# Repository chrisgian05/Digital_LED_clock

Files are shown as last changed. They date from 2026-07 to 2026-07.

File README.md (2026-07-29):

# Digital LED Clock

A 6-digit 7-segment clock (HH:MM:SS) built around an ATmega328P, an
external RTC, and a constant-current LED driver — split across two
custom PCBs I designed in KiCad. This was mostly an excuse to actually
use everything I've learned so far about digital electronics and
embedded C in one project I could see and touch, instead of another
breadboard that gets torn down at the end of the semester.

## What it does

- Shows time as HH:MM:SS across 6 seven-segment digits
- Keeps time with a DS3231 RTC (accurate even when the board is
  powered off, thanks to a coin cell)
- 4 buttons: set hour, set minute, reset seconds, and toggle to show
  the DS3231's built-in temperature reading instead of the time
- Multiplexed display — only one digit is physically powered at a
  time, cycled fast enough (~166Hz) that it looks fully lit

## Hardware

Two boards, connected by a short ribbon cable:

- **`clock_board`** — the "brains." ATmega328P, DS3231 RTC, a 74HC595
  shift register + 6 transistors for digit selection, an ISP header
  for programming, and the 4 push buttons.
- **`led_board`** — the "face." A TLC5916 constant-current LED driver
  feeding three 2-digit common-anode 7-segment modules (6 digits
  total), plus the transistor-switched power lines coming in from the
  clock board.

Full schematics and PCB layouts are in [`hardware/`](hardware/), one
subfolder per board. Both were designed from scratch in KiCad — no
dev-board shields, no premade modules other than the RTC/driver ICs
themselves.

## Firmware

Bare-metal AVR C — no Arduino core, straight `avr-libc` and direct
register access. I wanted to actually deal with I2C, timers, and
interrupts myself instead of hiding behind `Wire.h` and `digitalWrite`.

- **`twi.c`** — hardware I2C driver for talking to the DS3231
- **`ds3231.c`** — RTC register access (BCD conversion, get/set time, temperature)
- **`display.c`** — 7-segment font table + the Timer1 interrupt that handles
  digit multiplexing (bit-banging both the 74HC595 and TLC5916 shift chains)
- **`buttons.c`** — debounced button reads with auto-repeat on hold
- **`main.c`** — main loop tying it all together

All of it lives in [`firmware/`](firmware/), buildable with either the
included `Makefile` or `platformio.ini`.

## Status

Schematics and PCBs are designed; firmware is written and reviewed but
**not yet validated on the assembled board** (still waiting on
boards/soldering as of writing this). A couple of polarity assumptions
(digit-select active-high/low, segment driver active-high/low) are
flagged with `#define`s in `firmware/src/config.h` specifically because
they're easier to confirm with a multimeter on the real board than to
guess from a schematic.

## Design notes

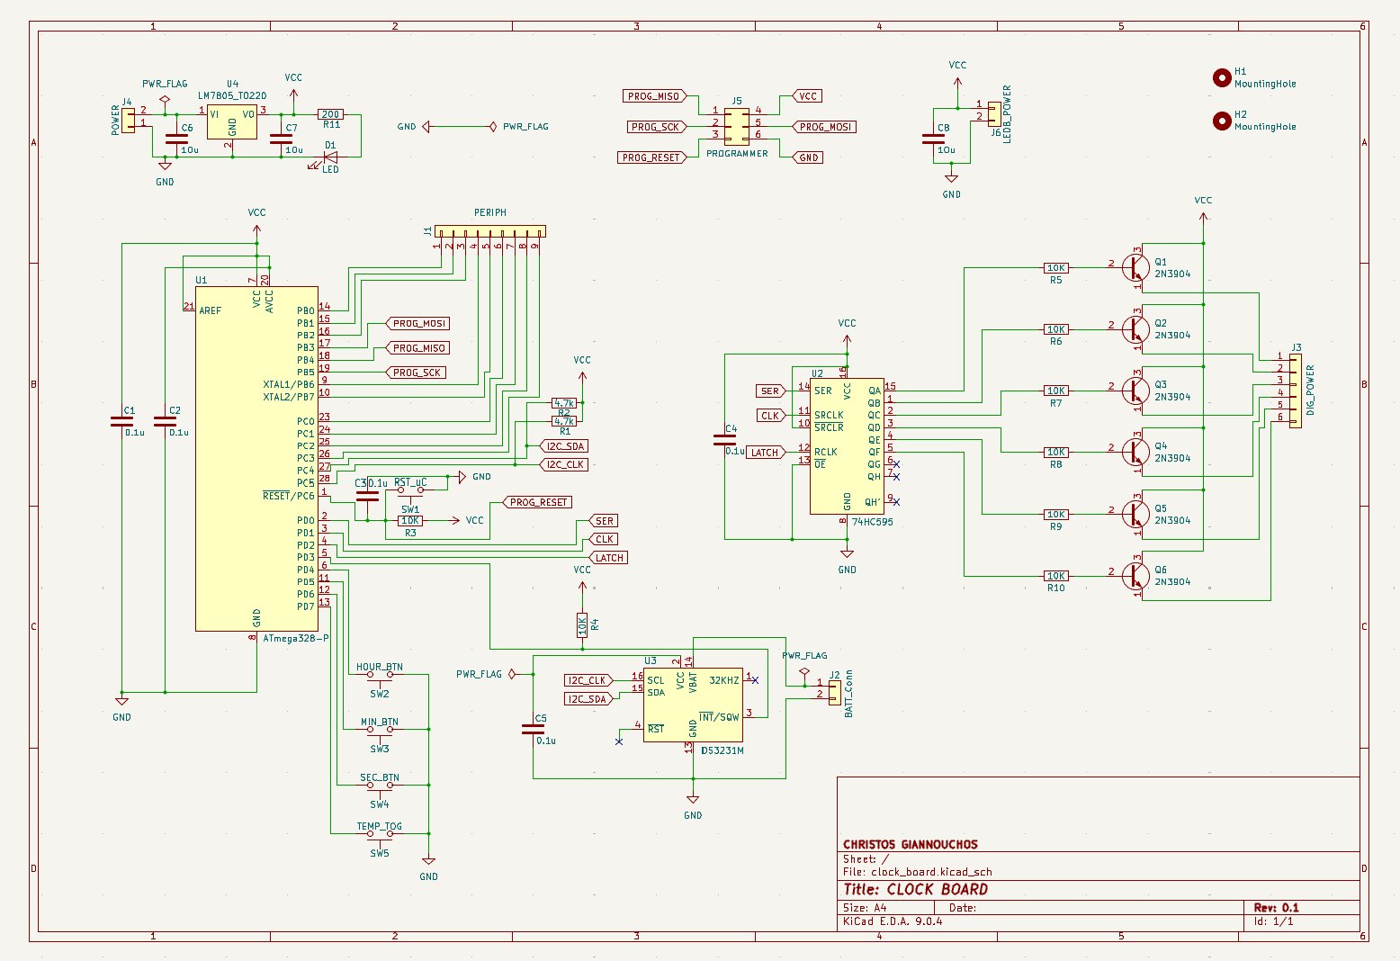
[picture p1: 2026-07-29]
hardware/clock_board/schematic.png

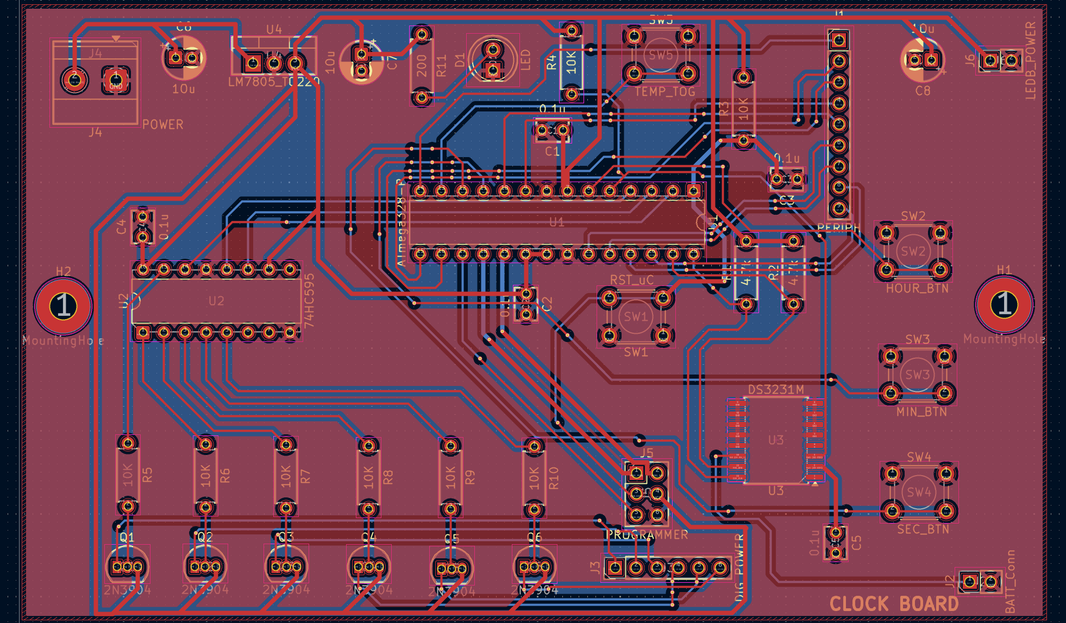
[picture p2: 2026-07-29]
hardware/clock_board/board.png

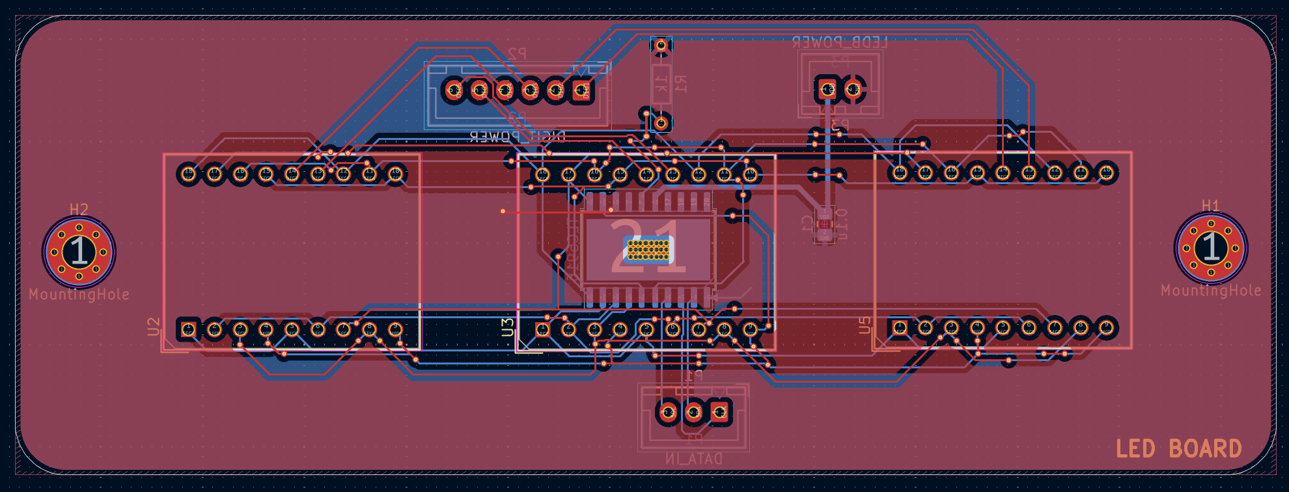
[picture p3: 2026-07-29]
hardware/led_board/board.png

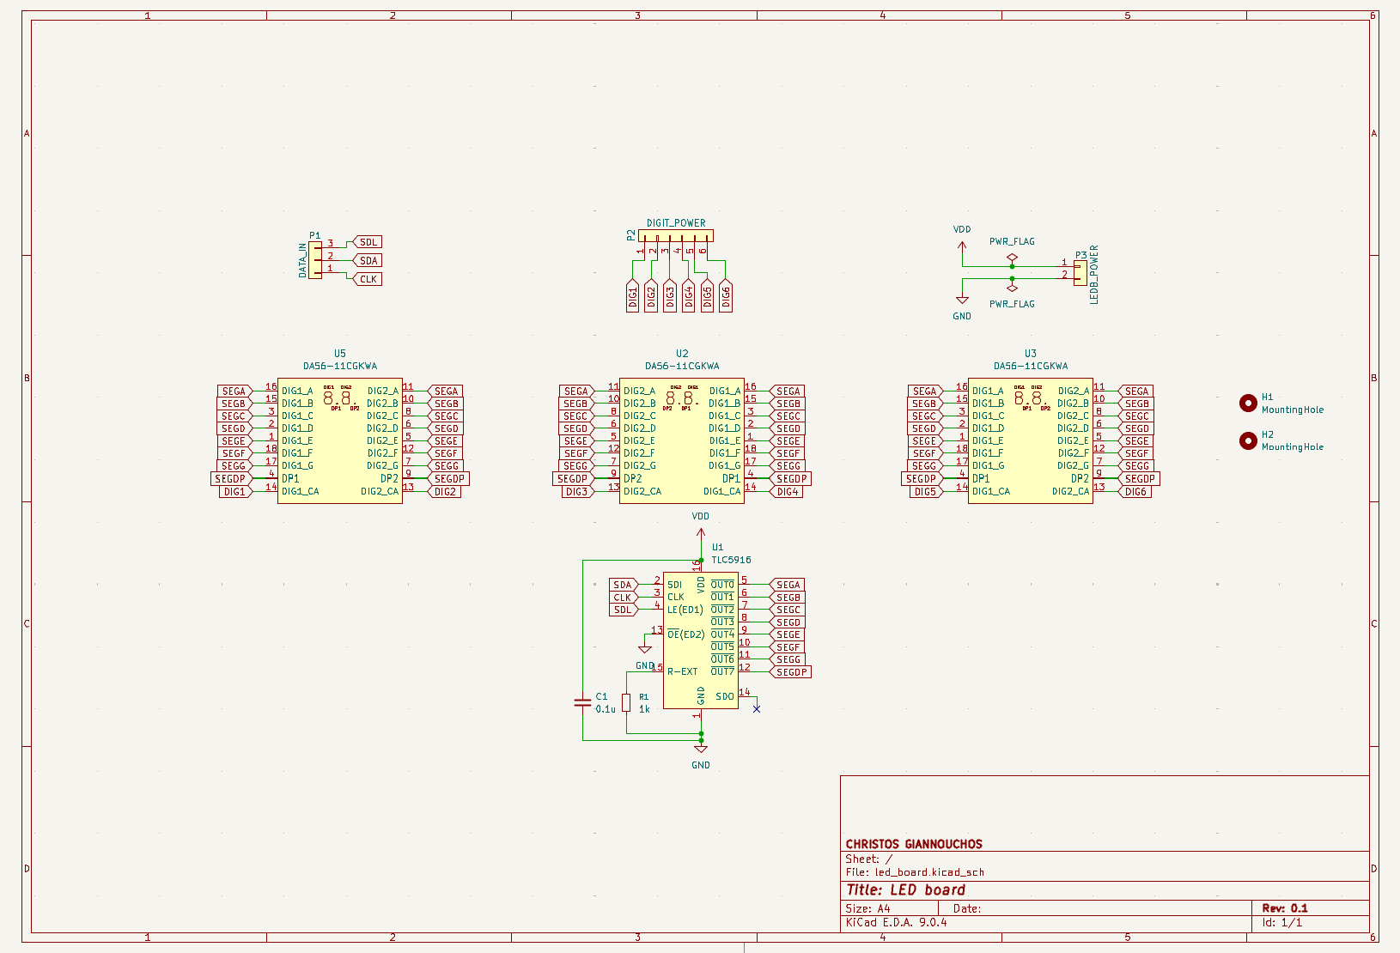
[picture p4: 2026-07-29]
hardware/led_board/schematic.png

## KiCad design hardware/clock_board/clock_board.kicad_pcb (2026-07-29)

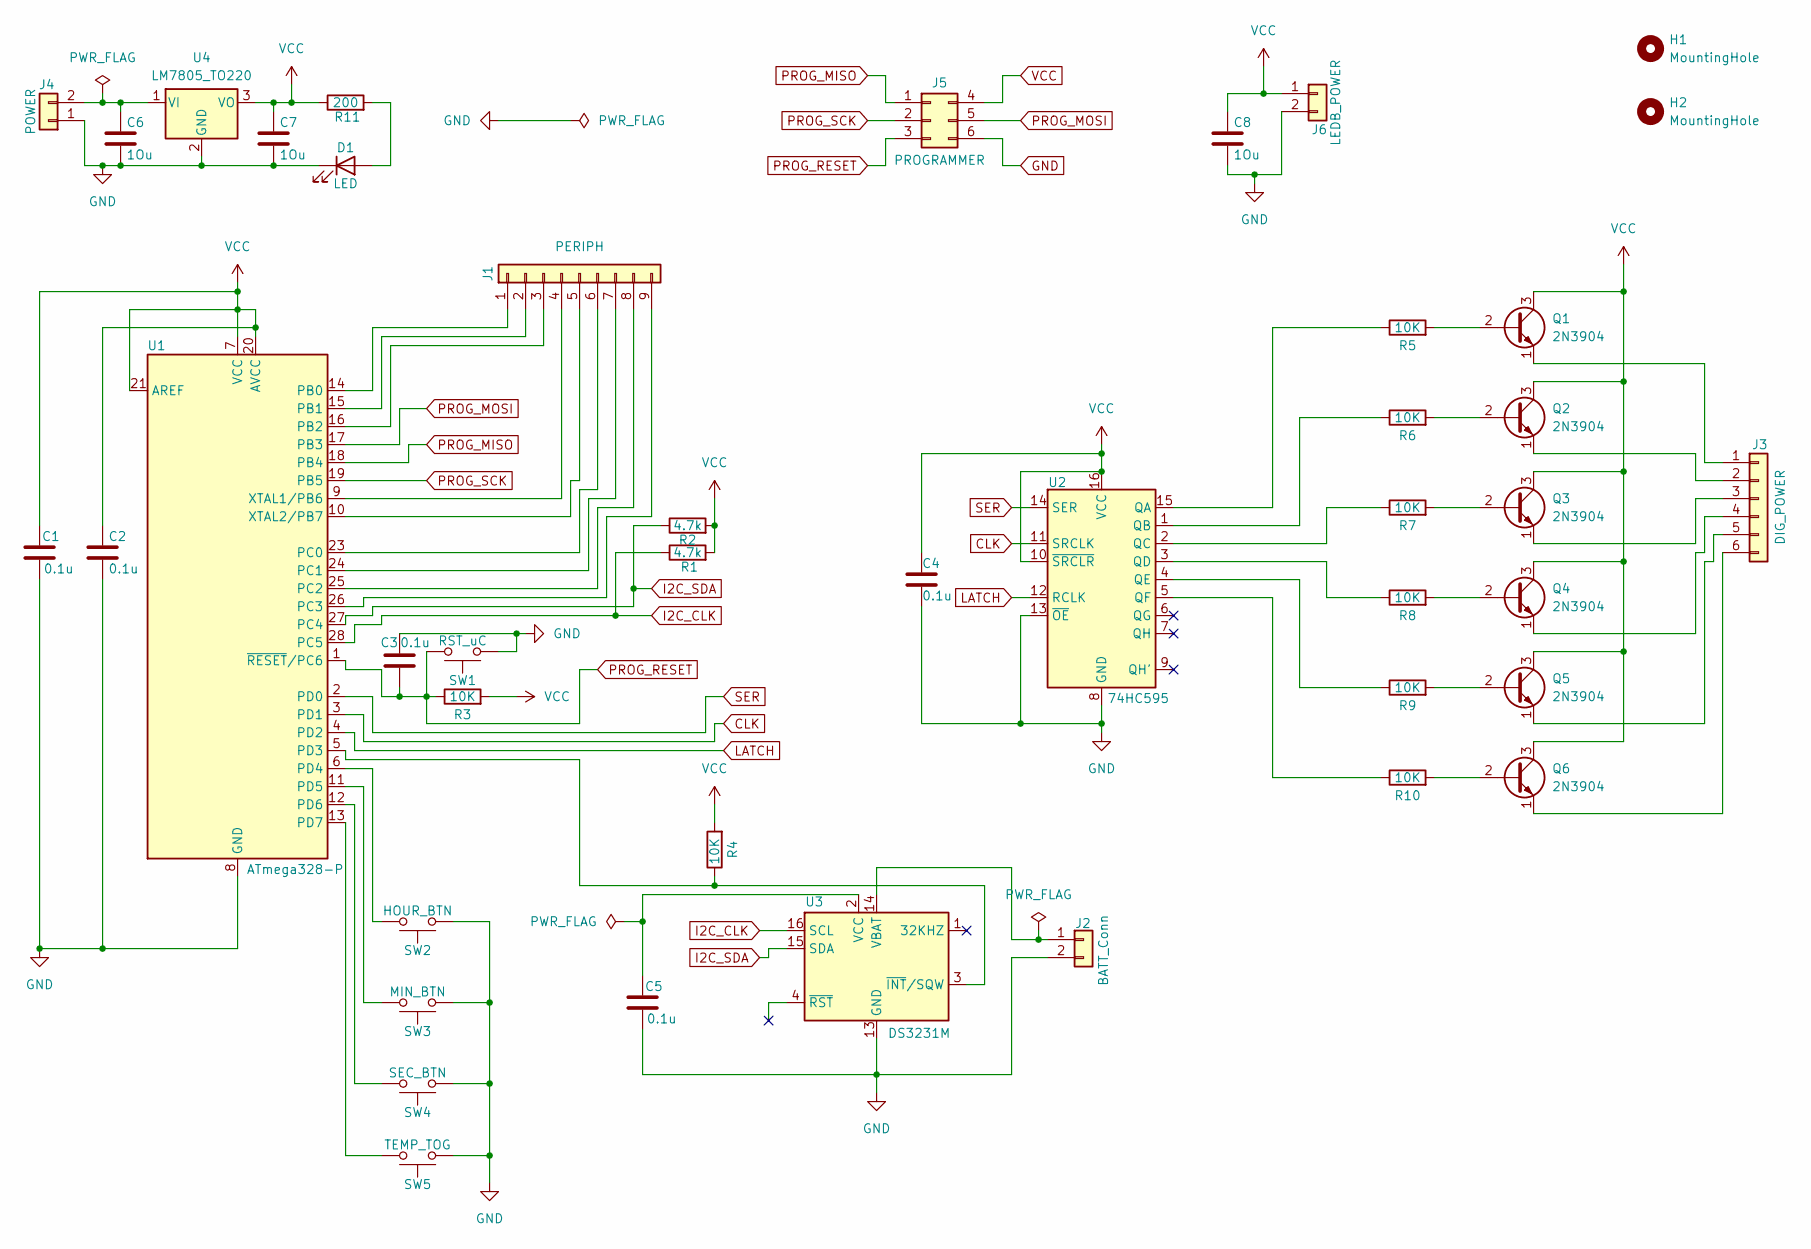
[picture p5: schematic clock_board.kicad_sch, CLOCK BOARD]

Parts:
C1, C2, C3, C4, C5: 0.1u; C_Disc_D3.8mm_W2.6mm_P2.50mm
C6, C7, C8: 1Ou; CP_Radial_D5.0mm_P2.00mm
D1: LED; LED_D5.0mm
H1, H2: MountingHole; MountingHole_3.2mm_M3_Pad
J1: PERIPH; PinHeader_1x09_P2.54mm_Vertical
J2: BATT_Conn; PinHeader_1x02_P2.54mm_Vertical
J3: DIG_POWER; PinHeader_1x06_P2.54mm_Vertical
J4: POWER; TerminalBlock_Phoenix_MKDS-1,5-2_1x02_P5.00mm_Horizontal
J5: PROGRAMMER; PinHeader_2x03_P2.54mm_Vertical
J6: LEDB_POWER; PinHeader_1x02_P2.54mm_Vertical
Q1, Q2, Q3, Q4, Q5, Q6: 2N3904; TO-92_Inline
R1, R2: 4.7k; R_Axial_DIN0207_L6.3mm_D2.5mm_P7.62mm_Horizontal
R3, R4, R5, R6, R7, R8, R9, R10: 10K; R_Axial_DIN0207_L6.3mm_D2.5mm_P7.62mm_Horizontal
R11: 200; R_Axial_DIN0207_L6.3mm_D2.5mm_P7.62mm_Horizontal
SW1: RST_uC; SW_PUSH_6mm_H5mm
SW2: HOUR_BTN; SW_PUSH_6mm_H5mm
SW3: MIN_BTN; SW_PUSH_6mm_H5mm
SW4: SEC_BTN; SW_PUSH_6mm_H5mm
SW5: TEMP_TOG; SW_PUSH_6mm_H5mm
U1: ATmega328-P; DIP-28_W7.62mm
U2: 74HC595; CERDIP-16_W7.62mm_SideBrazed
U3: DS3231M; SOIC-16W_7.5x10.3mm_P1.27mm
U4: LM7805_TO220; TO-220-3_Vertical

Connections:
CLK: U1.3 (PD1), U2.11 (SRCLK)
GND: C1.2, C2.2, C3.1, C4.2, C5.2, C6.2, C7.2, C8.2, D1.1 (K), J2.2, J4.1, J5.6, J6.2, SW1.1, SW2.1, SW3.1, SW4.1, SW5.1, U1.8 (GND), U1.22 (GND), U2.8 (GND), U2.13 (~OE), U3.5 (GND), U3.6 (GND), U3.7 (GND), U3.8 (GND), U3.9 (GND), U3.10 (GND), U3.11 (GND), U3.12 (GND), U3.13 (GND), U4.2 (GND)
I2C_CLK: R1.1, U1.28 (PC5), U3.16 (SCL)
I2C_SDA: R2.1, U1.27 (PC4), U3.15 (SDA)
LATCH: U1.4 (PD2), U2.12 (RCLK)
unnamed: D1.2 (A), R11.2
unnamed: J1.1, U1.14 (PB0)
unnamed: J1.2, U1.15 (PB1)
unnamed: J1.3, U1.16 (PB2)
unnamed: J1.4, U1.9 (XTAL1/PB6)
unnamed: J1.5, U1.10 (XTAL2/PB7)
unnamed: J1.6, U1.23 (PC0)
unnamed: J1.7, U1.24 (PC1)
unnamed: J1.8, U1.25 (PC2)
unnamed: J1.9, U1.26 (PC3)
unnamed: J2.1, U3.14 (VBAT)
unnamed: J3.1, Q1.1 (E)
unnamed: J3.2, Q2.1 (E)
unnamed: J3.3, Q3.1 (E)
unnamed: J3.4, Q4.1 (E)
unnamed: J3.5, Q5.1 (E)
unnamed: J3.6, Q6.1 (E)
unnamed: C6.1, J4.2, U4.1 (VI)
unnamed: Q1.2 (B), R5.2
unnamed: Q2.2 (B), R6.2
unnamed: Q3.2 (B), R7.2
unnamed: Q4.2 (B), R8.2
unnamed: Q5.2 (B), R9.2
unnamed: Q6.2 (B), R10.2
unnamed: R4.1, U1.5 (PD3), U3.3 (~INT/SQW)
unnamed: SW2.2, U1.6 (PD4)
unnamed: SW3.2, U1.11 (PD5)
unnamed: SW4.2, U1.12 (PD6)
unnamed: SW5.2, U1.13 (PD7)
unnamed: R5.1, U2.15 (QA)
unnamed: R6.1, U2.1 (QB)
unnamed: R7.1, U2.2 (QC)
unnamed: R8.1, U2.3 (QD)
unnamed: R9.1, U2.4 (QE)
unnamed: R10.1, U2.5 (QF)
unnamed: C5.1, U3.2 (VCC)
PROG_MISO: J5.1, U1.18 (PB4)
PROG_MOSI: J5.5, U1.17 (PB3)
PROG_RESET: C3.2, J5.3, R3.1, SW1.2, U1.1 (~RESET/PC6)
PROG_SCK: J5.2, U1.19 (PB5)
SER: U1.2 (PD0), U2.14 (SER)
VCC: C1.1, C2.1, C4.1, C7.1, C8.1, J5.4, J6.1, Q1.3 (C), Q2.3 (C), Q3.3 (C), Q4.3 (C), Q5.3 (C), Q6.3 (C), R1.2, R2.2, R3.2, R4.2, R11.1, U1.7 (VCC), U1.20 (AVCC), U1.21 (AREF), U2.10 (~SRCLR), U2.16 (VCC), U4.3 (VO)

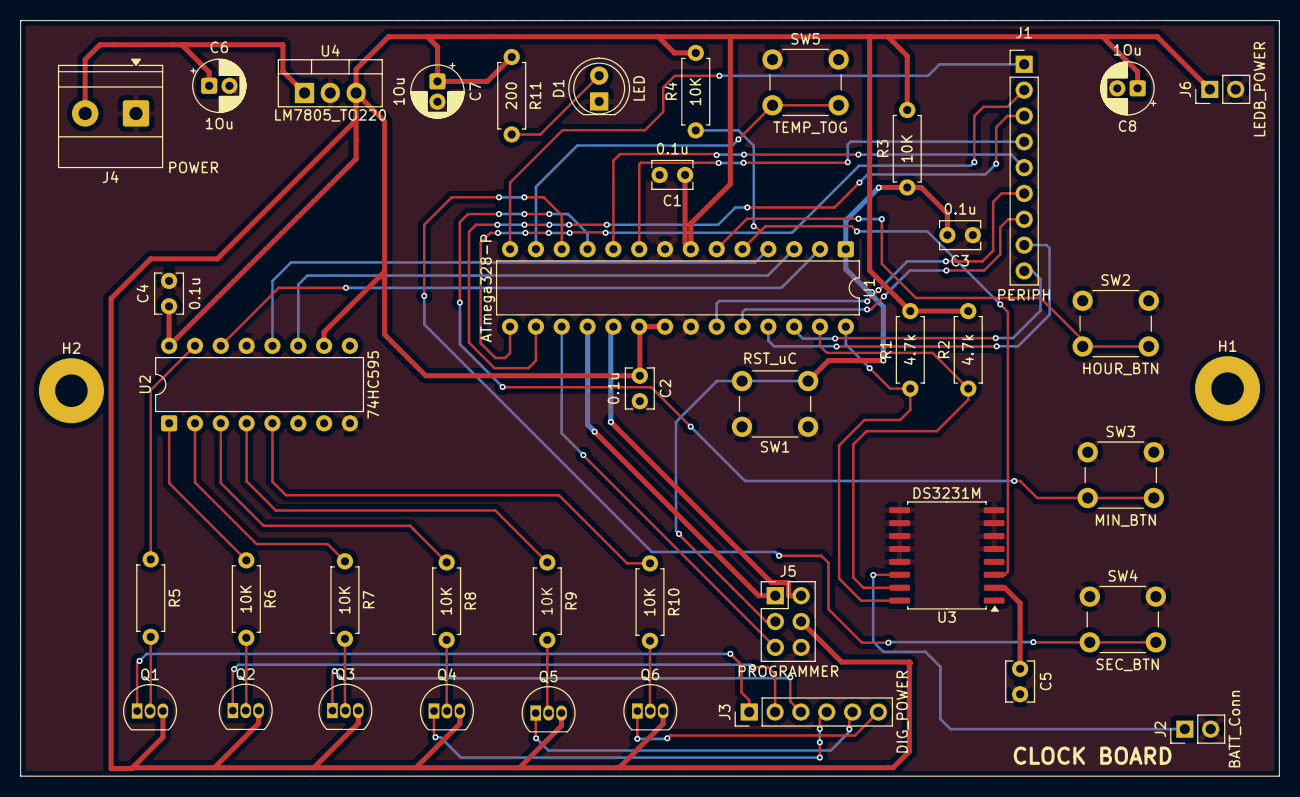
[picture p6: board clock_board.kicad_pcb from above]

Board: 2 copper layers, 123.8 x 74.3 mm, 43 parts (0 on the bottom side), 47 nets.

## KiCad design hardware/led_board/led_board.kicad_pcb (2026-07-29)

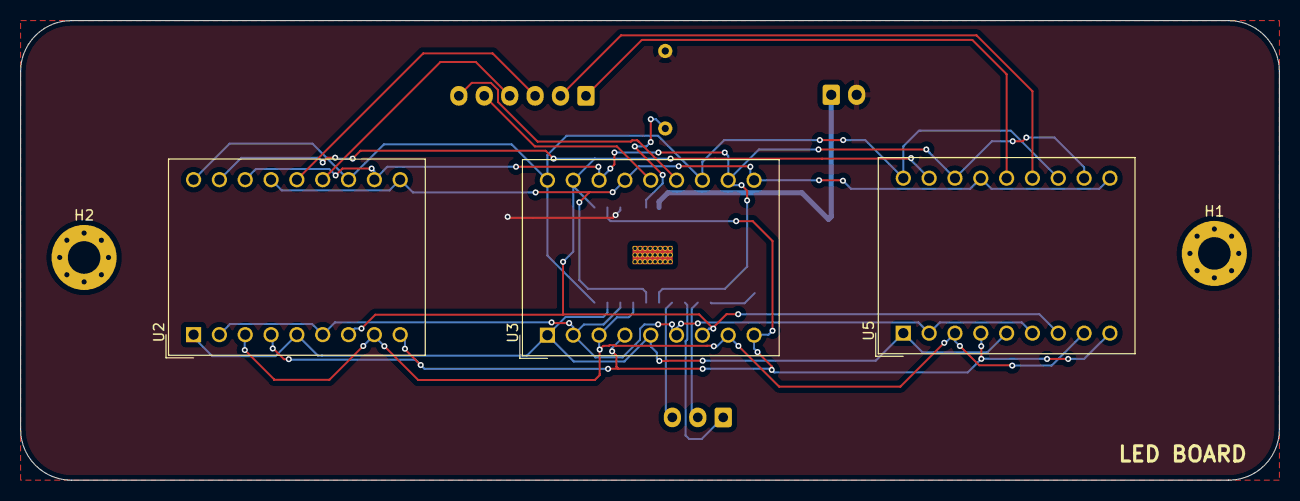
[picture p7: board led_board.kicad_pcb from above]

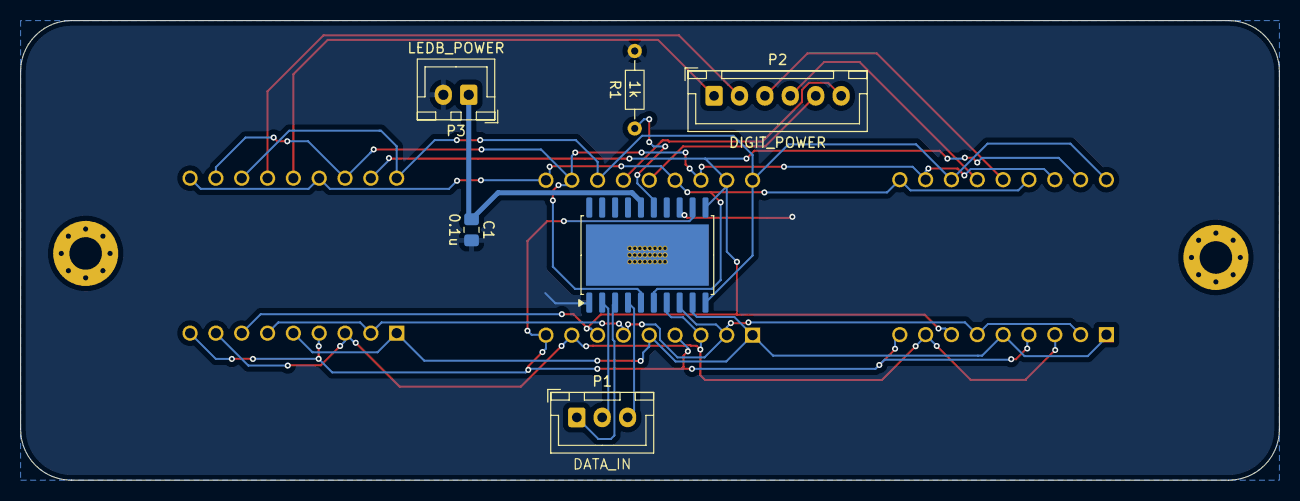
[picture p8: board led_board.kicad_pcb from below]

Board: 2 copper layers, 123.8 x 45.2 mm, 11 parts (6 on the bottom side), 20 nets.

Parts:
C1: 0.1u; C_0805_2012Metric_Pad1.18x1.45mm_HandSolder
H1, H2: MountingHole; MountingHole_3.2mm_M3_Pad_Via
P1: DATA_IN; JST_XH_B3B-XH-A_1x03_P2.50mm_Vertical
P2: DIGIT_POWER; JST_XH_B6B-XH-A_1x06_P2.50mm_Vertical
P3: LEDB_POWER; JST_XH_B2B-XH-A_1x02_P2.50mm_Vertical
R1: 1k; R_Axial_DIN0204_L3.6mm_D1.6mm_P7.62mm_Horizontal
U1: TLC5916; SO-20-1EP_7.52x12.825mm_P1.27mm_EP6.045x12.09mm_Mask3.56x4.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
U2, U3, U5: DA56-11CGKWA

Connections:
CLK: P1.1, U1.3 (CLK)
DIG1: P2.1, U5.14 (DIG1_CA)
DIG2: P2.2, U5.13 (DIG2_CA)
DIG3: P2.3, U2.14 (DIG1_CA)
DIG4: P2.4, U2.13 (DIG2_CA)
DIG5: P2.5, U3.14 (DIG1_CA)
DIG6: P2.6, U3.13 (DIG2_CA)
GND: C1.2, P3.2, R1.2, U1.1 (GND), U1.13 (~OE(ED2))
unnamed: R1.1, U1.15 (R-EXT)
SDA: P1.2, U1.2 (SDI)
SDL: P1.3, U1.4 (LE(ED1))
SEGA: U1.5 (~OUT0), U2.11 (DIG2_A), U2.16 (DIG1_A), U3.11 (DIG2_A), U3.16 (DIG1_A), U5.11 (DIG2_A), U5.16 (DIG1_A)
SEGB: U1.6 (~OUT1), U2.10 (DIG2_B), U2.15 (DIG1_B), U3.10 (DIG2_B), U3.15 (DIG1_B), U5.10 (DIG2_B), U5.15 (DIG1_B)
SEGC: U1.7 (~OUT2), U2.3 (DIG1_C), U2.8 (DIG2_C), U3.3 (DIG1_C), U3.8 (DIG2_C), U5.3 (DIG1_C), U5.8 (DIG2_C)
SEGD: U1.8 (~OUT3), U2.2 (DIG1_D), U2.6 (DIG2_D), U3.2 (DIG1_D), U3.6 (DIG2_D), U5.2 (DIG1_D), U5.6 (DIG2_D)
SEGDP: U1.12 (~OUT7), U2.4 (DP1), U2.9 (DP2), U3.4 (DP1), U3.9 (DP2), U5.4 (DP1), U5.9 (DP2)
SEGE: U1.9 (~OUT4), U2.1 (DIG1_E), U2.5 (DIG2_E), U3.1 (DIG1_E), U3.5 (DIG2_E), U5.1 (DIG1_E), U5.5 (DIG2_E)
SEGF: U1.10 (~OUT5), U2.12 (DIG2_F), U2.18 (DIG1_F), U3.12 (DIG2_F), U3.18 (DIG1_F), U5.12 (DIG2_F), U5.18 (DIG1_F)
SEGG: U1.11 (~OUT6), U2.7 (DIG2_G), U2.17 (DIG1_G), U3.7 (DIG2_G), U3.17 (DIG1_G), U5.7 (DIG2_G), U5.17 (DIG1_G)
VDD: C1.1, P3.1, U1.16 (VDD)

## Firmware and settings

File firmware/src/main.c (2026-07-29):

#include "config.h"
#include "twi.h"
#include "ds3231.h"
#include "display.h"
#include "buttons.h"
#include <avr/interrupt.h>

#define RTC_POLL_INTERVAL_MS   200  /* how often we re-read HH:MM:SS   */
#define TEMP_POLL_INTERVAL_MS  1000 /* DS3231 only updates temp ~64s   */

int main(void)
{
    twi_init();
    ds3231_init();      /* if this returns 0, the RTC isn't answering -
                          * time will just read back as whatever junk
                          * twi_read_regs left in the struct (likely all
                          * zero), which is harmless, it'll just show
                          * 00:00:00 until you fix the wiring. */
    display_init();
    buttons_init();
    sei();               /* enable interrupts -> Timer1 multiplex ISR starts */

    rtc_time_t cur_time = {0, 0, 0};
    int16_t    cur_tenths_c = 0;
    uint8_t    show_temp = 0;

    uint32_t last_rtc_poll  = 0;
    uint32_t last_temp_poll = 0;

    for (;;) {
        uint8_t events = buttons_poll();
        uint8_t time_changed = 0;

        if (events & BTN_EVT_HOUR) {
            cur_time.hour = (uint8_t)((cur_time.hour + 1) % 24);
            time_changed = 1;
        }
        if (events & BTN_EVT_MIN) {
            cur_time.minute = (uint8_t)((cur_time.minute + 1) % 60);
            time_changed = 1;
        }
        if (events & BTN_EVT_SEC) {
            /* Classic "seconds reset" behaviour: snaps the RTC to the
             * top of the current minute. Change this to an increment
             * like the others if you'd rather it count seconds up. */
            cur_time.second = 0;
            time_changed = 1;
        }
        if (events & BTN_EVT_TEMP_TOG) {
            show_temp = (uint8_t)!show_temp;
        }

        if (time_changed) {
            ds3231_set_time(&cur_time);
            last_rtc_poll = millis(); 
        } else if ((millis() - last_rtc_poll) >= RTC_POLL_INTERVAL_MS) {
            ds3231_get_time(&cur_time);
            last_rtc_poll = millis();
        }

        if ((millis() - last_temp_poll) >= TEMP_POLL_INTERVAL_MS) {
            ds3231_get_temp_tenths(&cur_tenths_c);
            last_temp_poll = millis();
        }

        if (show_temp) {
            display_show_temp(cur_tenths_c);
        } else {
            uint8_t colon_on = (uint8_t)((cur_time.second & 0x01) == 0);
            display_show_time(cur_time.hour, cur_time.minute,
                               cur_time.second, colon_on);
        }
    }
}

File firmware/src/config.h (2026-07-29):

#ifndef CONFIG_H
#define CONFIG_H

#ifndef F_CPU
#define F_CPU 8000000UL
#endif

/*74HC595 : digit select (clock board, local)*/
#define DIG595_PORT   PORTD
#define DIG595_DDR    DDRD
#define DIG595_SER    PD0   
#define DIG595_CLK    PD1   
#define DIG595_LATCH  PD2   

#define DIGIT_ACTIVE_HIGH 1

/*TLC5916 : segment data (over J1 PERIPH to the LED board)*/
#define SEG_PORT      PORTC
#define SEG_DDR       DDRC
#define SEG_SDI       PC0  
#define SEG_CLK       PC1   
#define SEG_LE        PC2  

#define SEGMENT_ACTIVE_HIGH 1 

/*Buttons (active LOW, using internal pull-ups)*/
#define BTN_PORT      PORTD
#define BTN_DDR       DDRD
#define BTN_PIN_REG   PIND
#define BTN_HOUR      PD4   
#define BTN_MIN       PD5   
#define BTN_SEC       PD6   
#define BTN_TEMP_TOG  PD7   

#define NUM_DIGITS 6

/* Refresh: each digit gets a 1 ms on-time slice -> ~166 Hz full-frame
 * refresh, well above the flicker threshold. Also used as a 1 kHz
 * system tick for button debouncing. */
#define REFRESH_TICK_HZ 1000UL

/* I2C bus speed to the DS3231 */
#define TWI_SCL_FREQ 100000UL /*100kHz*/

#endif 

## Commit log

2026-07-29 Rename Στιγμιότυπο οθόνης 2026-07-29 155355.png to schematic
2026-07-29 Rename Στιγμιότυπο οθόνης 2026-07-29 155513.png to board
